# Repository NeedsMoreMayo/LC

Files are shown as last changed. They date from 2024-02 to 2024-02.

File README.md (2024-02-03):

# LC meter
The LC meter in this project is based on a popular design that's found on numerous websites. I added an external GPSDO input to use as stable clock reference and a second input so the meter can be used as a frequency counter.

## Principle of operation

## Major components
- The display is a 1602A (ver 5.5) with an I2C PCF8574 expander from aliExpress.
- uC is AVR32DB28

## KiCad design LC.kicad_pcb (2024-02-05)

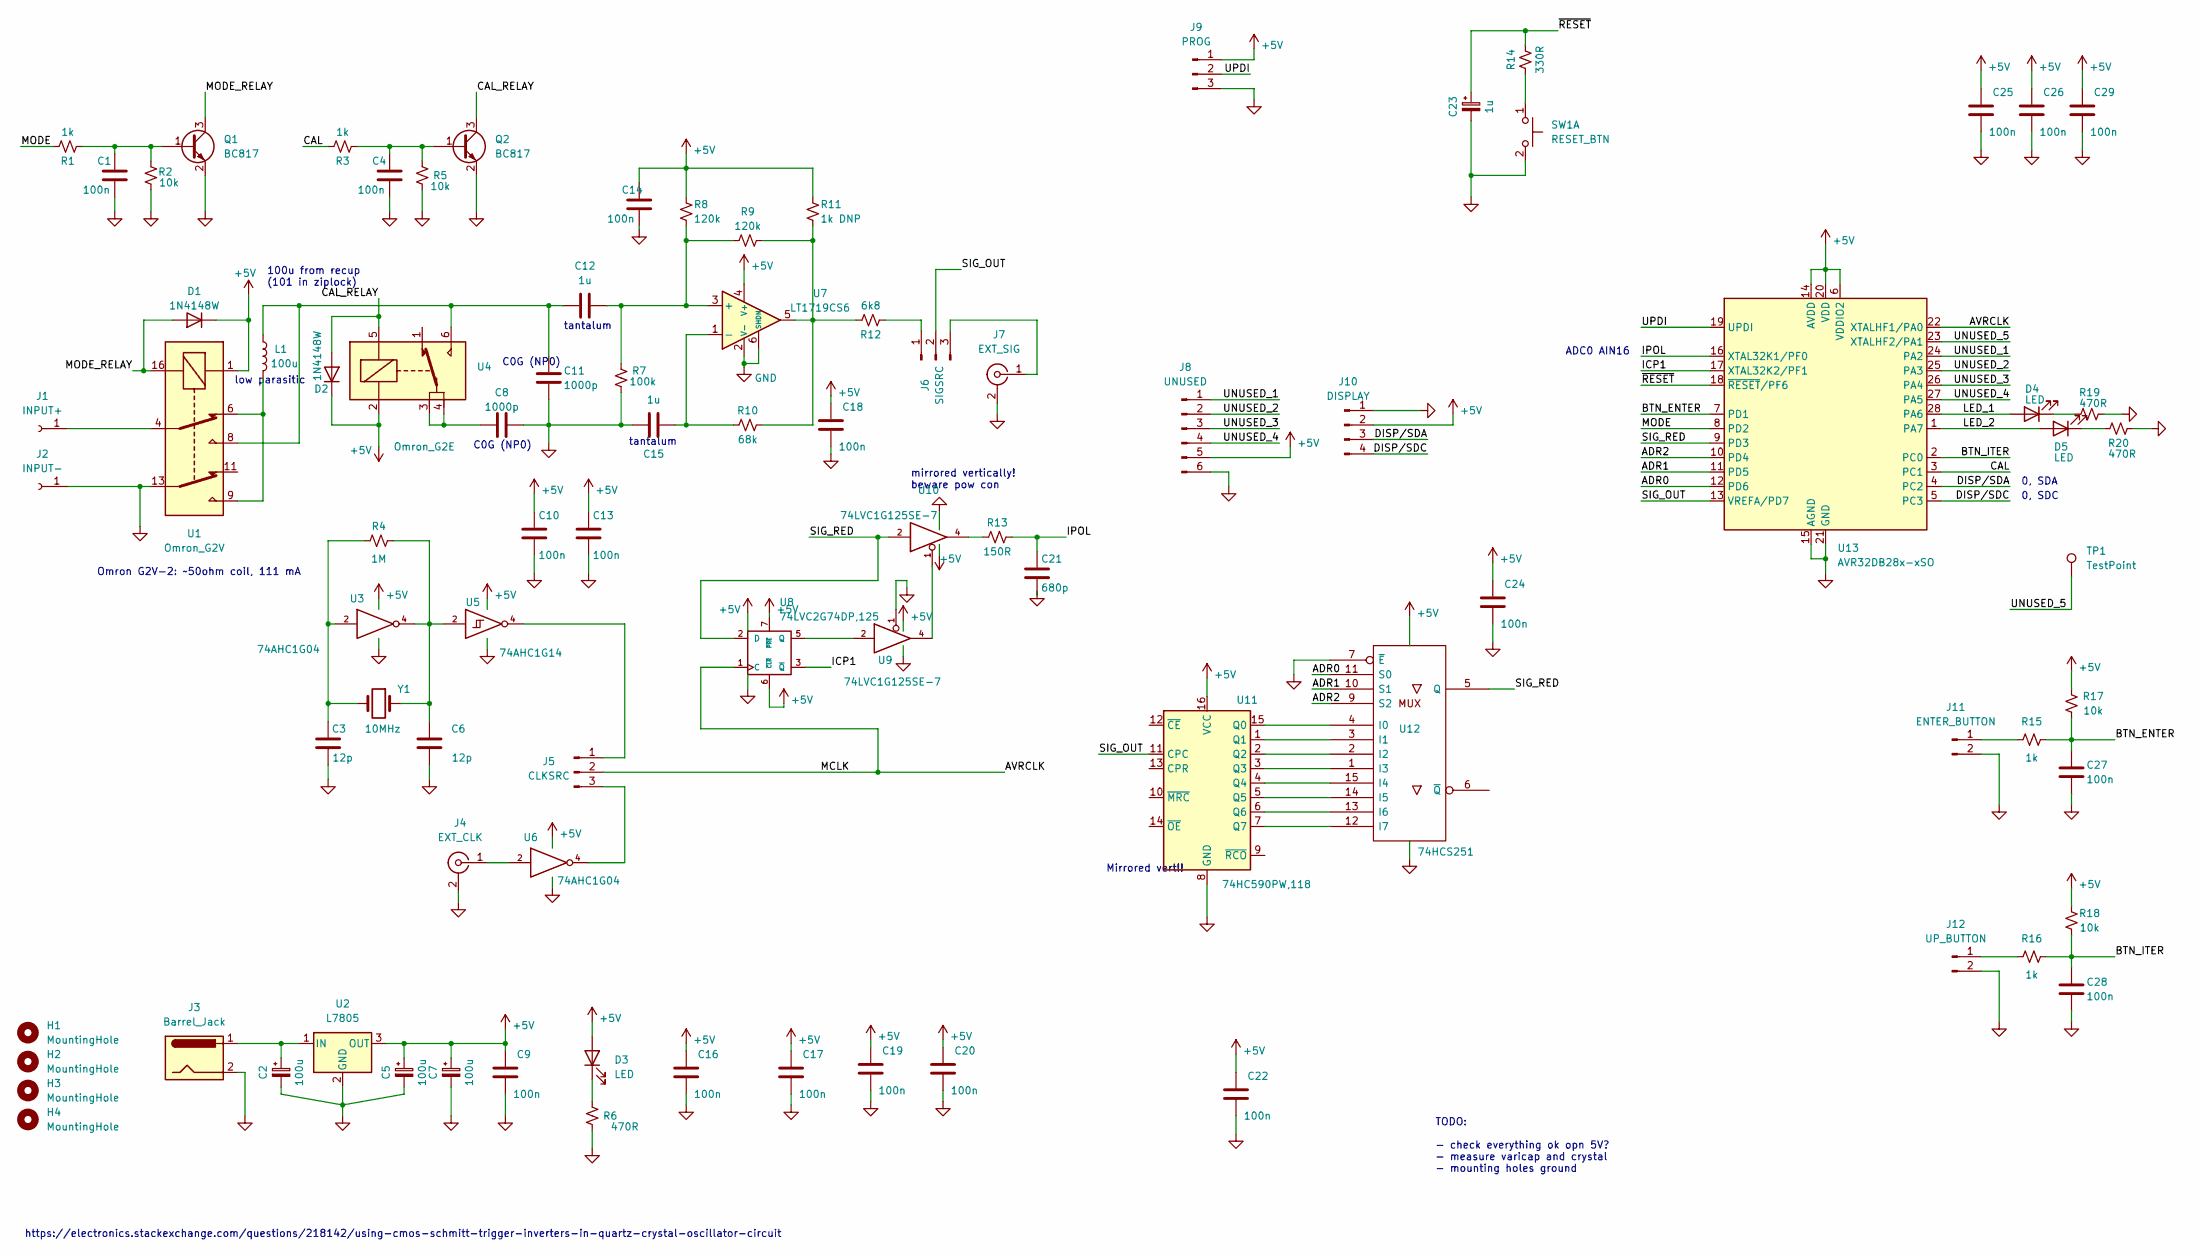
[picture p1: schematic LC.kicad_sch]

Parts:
C1, C4, C9, C10, C13, C14, C16, C17, C18, C19, C20, C22, C24, C25, C26, C27, C28, C29: 100n; C_0805_2012Metric_Pad1.18x1.45mm_HandSolder
C2, C5, C7: 100u; CP_Radial_D5.0mm_P2.00mm
C3, C6: 12p; C_0805_2012Metric_Pad1.18x1.45mm_HandSolder
C8, C11: 1000p; C_0805_2012Metric_Pad1.18x1.45mm_HandSolder
C12, C15, C23: 1u; C_0805_2012Metric_Pad1.18x1.45mm_HandSolder
C21: 680p; C_0805_2012Metric_Pad1.18x1.45mm_HandSolder
D1, D2: 1N4148W; D_SOD-123
D3, D4, D5: LED; LED_1206_3216Metric
H1, H2, H3, H4: MountingHole; MountingHole_3.2mm_M3_Pad
J1: INPUT+; Pin_D1.0mm_L10.0mm
J2: INPUT-; Pin_D1.0mm_L10.0mm
J3: Barrel_Jack; BarrelJack_GCT_DCJ200-10-A_Horizontal
J4: EXT_CLK; U.FL_Molex_MCRF_73412-0110_Vertical
J5: CLKSRC; PinHeader_1x03_P2.54mm_Vertical
J6: SIGSRC; PinHeader_1x03_P2.54mm_Vertical
J7: EXT_SIG; U.FL_Molex_MCRF_73412-0110_Vertical
J8: UNUSED; PinHeader_2x03_P2.54mm_Vertical
J9: PROG; PinHeader_1x03_P2.54mm_Vertical
J10: DISPLAY; PinHeader_1x04_P2.54mm_Vertical
J11: ENTER_BUTTON; PinHeader_1x02_P2.54mm_Vertical
J12: UP_BUTTON; PinHeader_1x02_P2.54mm_Vertical
L1: 100u; L_Coilcraft_LPS5030
Q1, Q2: BC817; SOT-23
R1, R3, R15, R16: 1k; R_0805_2012Metric_Pad1.20x1.40mm_HandSolder
R2, R5, R17, R18: 10k; R_0805_2012Metric_Pad1.20x1.40mm_HandSolder
R4: 1M; R_0805_2012Metric_Pad1.20x1.40mm_HandSolder
R6, R19, R20: 470R; R_0805_2012Metric_Pad1.20x1.40mm_HandSolder
R7: 100k; R_0805_2012Metric_Pad1.20x1.40mm_HandSolder
R8, R9: 120k; R_0805_2012Metric_Pad1.20x1.40mm_HandSolder
R10: 68k; R_0805_2012Metric_Pad1.20x1.40mm_HandSolder
R11: 1k DNP; R_0805_2012Metric_Pad1.20x1.40mm_HandSolder
R12: 6k8; R_0805_2012Metric_Pad1.20x1.40mm_HandSolder
R13: 150R; R_0805_2012Metric_Pad1.20x1.40mm_HandSolder
R14: 330R; R_0805_2012Metric_Pad1.20x1.40mm_HandSolder
SW1: RESET_BTN; BUTTON_5X5
TP1: TestPoint; TestPoint_THTPad_1.0x1.0mm_Drill0.5mm
U1: Omron_G2V; Omron G2V-2
U2: L7805; TO-220-3_Vertical
U3, U6: 74AHC1G04; SOT-23-5_HandSoldering
U4: Omron_G2E; Omron G2E
U5: 74AHC1G14; SOT-23-5_HandSoldering
U7: LT1719CS6; SOT-23-6
U8: 74LVC2G74DP,125; TSSOP-8_3x3mm_P0.65mm
U9, U10: 74LVC1G125SE-7; SOT-353_SC-70-5
U11: 74HC590PW,118; TSSOP-16_4.4x5mm_P0.65mm
U12: 74HCS251; SOIC-16_4.55x10.3mm_P1.27mm
U13: AVR32DB28x-xSO; SOIC-28W_7.5x17.9mm_P1.27mm
Y1: 10MHz; Crystal_HC49-4H_Vertical

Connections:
+5V: C5.1, C7.1, C9.2, C10.2, C13.2, C14.2, C16.2, C17.2, C18.2, C19.2, C20.2, C22.2, C24.2, C25.2, C26.2, C29.2, D1.1 (K), D2.1 (K), D3.2 (A), J8.5, J9.1, J10.2, R8.2, R11.2, R17.1, R18.1, U1.1, U2.3 (OUT), U3.5 (VCC), U4.2, U5.5 (VCC), U6.5 (VCC), U7.4 (V+), U8.6 (~CLR), U8.7 (~PRE), U8.8 (VCC), U9.5 (VCC), U10.5 (VCC), U11.16 (VCC), U12.16 (VCC), U13.6 (VDDIO2), U13.14 (AVDD), U13.20 (VDD)
/ADR0: U12.11 (S0), U13.12 (PD6)
/ADR1: U12.10 (S1), U13.11 (PD5)
/ADR2: U12.9 (S2), U13.10 (PD4)
/AVRCLK: J5.2, U8.1 (C), U13.22 (XTALHF1/PA0)
/BTN_ENTER: C27.2, R15.2, R17.2, U13.7 (PD1)
/BTN_ITER: C28.2, R16.2, R18.2, U13.2 (PC0)
/CAL: R3.2, U13.3 (PC1)
/CAL_RELAY: D2.2 (A), Q2.3 (C), U4.5
/DISP/SDA: J10.3, U13.4 (PC2)
/DISP/SDC: J10.4, U13.5 (PC3)
/ICP1: U8.3 (~Q), U13.17 (XTAL32K2/PF1)
/IPOL: C21.2, R13.1, U13.16 (XTAL32K1/PF0)
/LED_1: D4.2 (A), U13.28 (PA6)
/LED_2: D5.2 (A), U13.1 (PA7)
/MODE: R1.2, U13.8 (PD2)
/MODE_RELAY: D1.2 (A), Q1.3 (C), U1.16
/SIG_OUT: J6.2, U11.11 (CPC), U13.13 (VREFA/PD7)
/SIG_RED: U8.2 (D), U10.2, U12.5 (Q), U13.9 (PD3)
/UNUSED_1: J8.1, U13.24 (PA2)
/UNUSED_2: J8.2, U13.25 (PA3)
/UNUSED_3: J8.3, U13.26 (PA4)
/UNUSED_4: J8.4, U13.27 (PA5)
/UNUSED_5: TP1.1, U13.23 (XTALHF2/PA1)
/UPDI: J9.2, U13.19 (UPDI)
/~RESET: C23.1, R14.2, U13.18 (~RESET/PF6)
GND: C1.1, C2.2, C3.2, C4.1, C5.2, C6.2, C7.2, C8.1, C9.1, C10.1, C11.1, C13.1, C14.1, C15.1, C16.1, C17.1, C18.1, C19.1, C20.1, C21.1, C22.1, C23.2, C24.1, C25.1, C26.1, C27.1, C28.1, C29.1, J2.1, J3.2, J4.2 (Ext), J7.2 (Ext), J8.6, J9.3, J10.1, J11.2, J12.2, Q1.2 (E), Q2.2 (E), R2.2, R5.2, R6.2, R7.1, R19.2, R20.2, SW1.2 (D), U1.13, U2.2 (GND), U3.3 (GND), U5.3 (GND), U6.3 (GND), U7.2 (V-), U7.6 (SHDN), U8.4 (GND), U9.1, U9.3 (GND), U10.3 (GND), U11.8 (GND), U12.7 (~E), U12.8 (GND), U13.15 (AGND), U13.21 (GND)
unnamed: C1.2, Q1.1 (B), R1.1, R2.1
unnamed: C2.1, J3.1, U2.1 (IN)
unnamed: C3.1, R4.1, U3.2, Y1.2
unnamed: C4.2, Q2.1 (B), R3.1, R5.1
unnamed: C6.1, R4.2, U3.4, U5.2, Y1.1
unnamed: C8.2, U4.3, U4.4
unnamed: C11.2, C12.1, L1.1, U1.8, U4.6
unnamed: C12.2, R7.2, R8.1, R9.1, U7.3 (+)
unnamed: C15.2, R10.1, U7.1 (-)
unnamed: D3.1 (K), R6.1
unnamed: D4.1 (K), R19.1
unnamed: D5.1 (K), R20.1
unnamed: J1.1, U1.4
unnamed: J4.1 (In), U6.2
unnamed: J5.1, U5.4
unnamed: J5.3, U6.4
unnamed: J6.1, R12.1
unnamed: J6.3, J7.1 (In)
unnamed: J11.1, R15.1
unnamed: J12.1, R16.1
unnamed: L1.2, U1.6, U1.9
unnamed: R9.2, R10.2, R11.1, R12.2, U7.5
unnamed: R13.2, U10.4
unnamed: R14.1, SW1.1 (C)
unnamed: U8.5 (Q), U9.2
unnamed: U9.4, U10.1
unnamed: U11.1 (Q1), U12.3 (I1)
unnamed: U11.2 (Q2), U12.2 (I2)
unnamed: U11.3 (Q3), U12.1 (I3)
unnamed: U11.4 (Q4), U12.15 (I4)
unnamed: U11.5 (Q5), U12.14 (I5)
unnamed: U11.6 (Q6), U12.13 (I6)
unnamed: U11.7 (Q7), U12.12 (I7)
unnamed: U11.15 (Q0), U12.4 (I0)

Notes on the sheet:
100u from recup (101 in ziplock)
C0G (NP0)
mirrored vertically! beware pow con
low parasitic
0, SDC
TODO: - check everything ok opn 5V? - measure varicap and crystal - mounting holes ground
tantalum
Mirrored vert!!
Omron G2V-2: ~50ohm coil, 111 mA
ADC0 AIN16
0, SDA
https://electronics.stackexchange.com/questions/218142/using-cmos-schmitt-trigger-inverters-in-quartz-crystal-oscillator-circuit

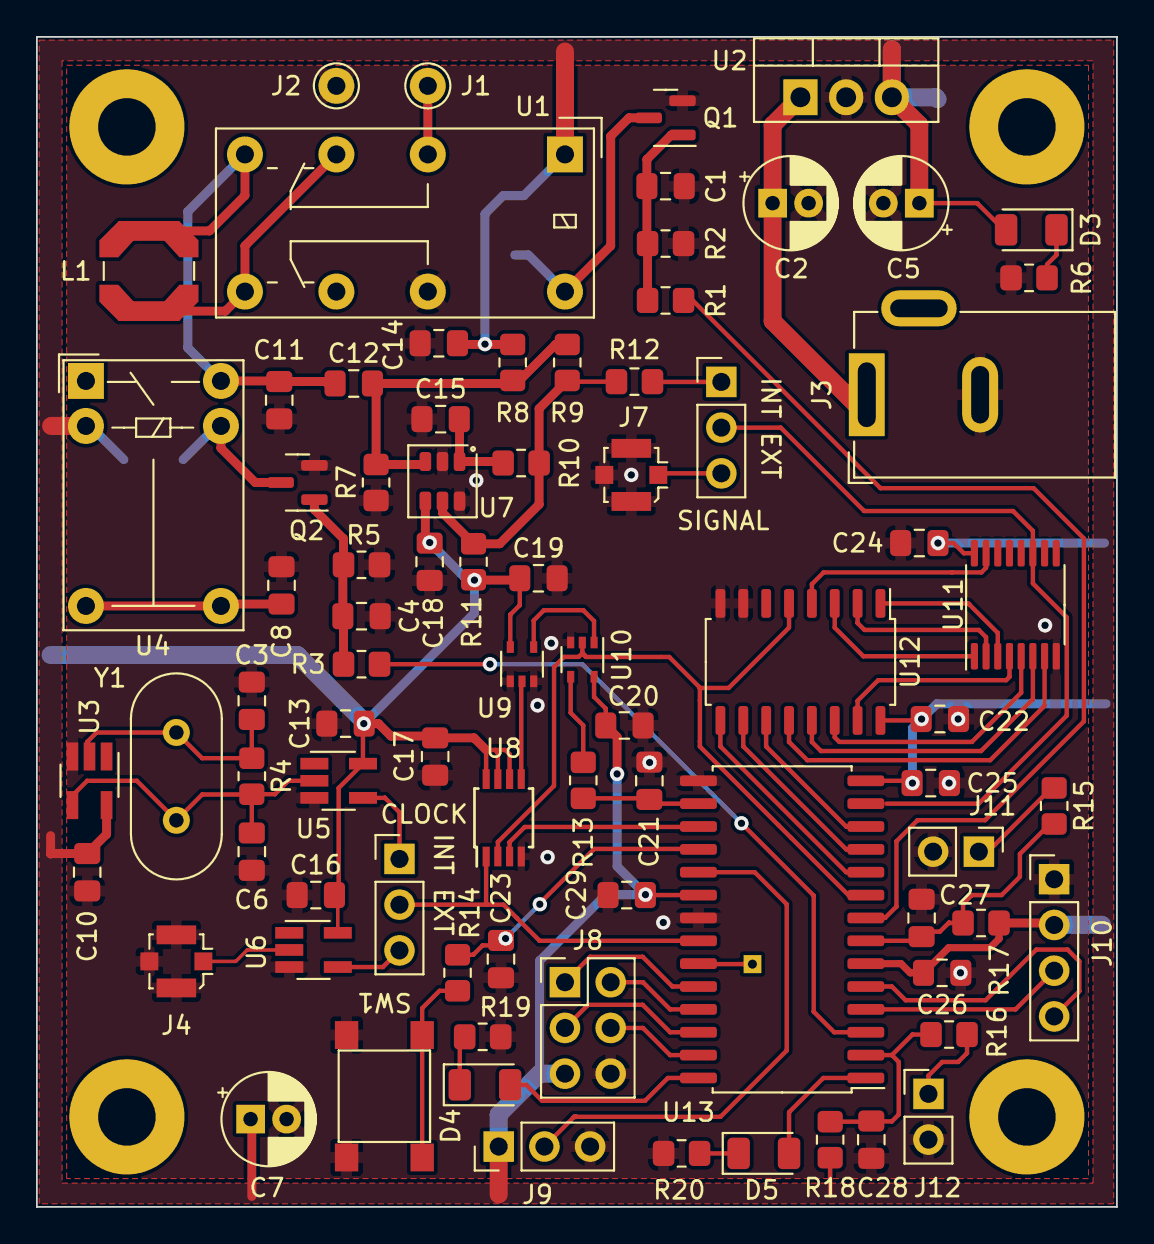
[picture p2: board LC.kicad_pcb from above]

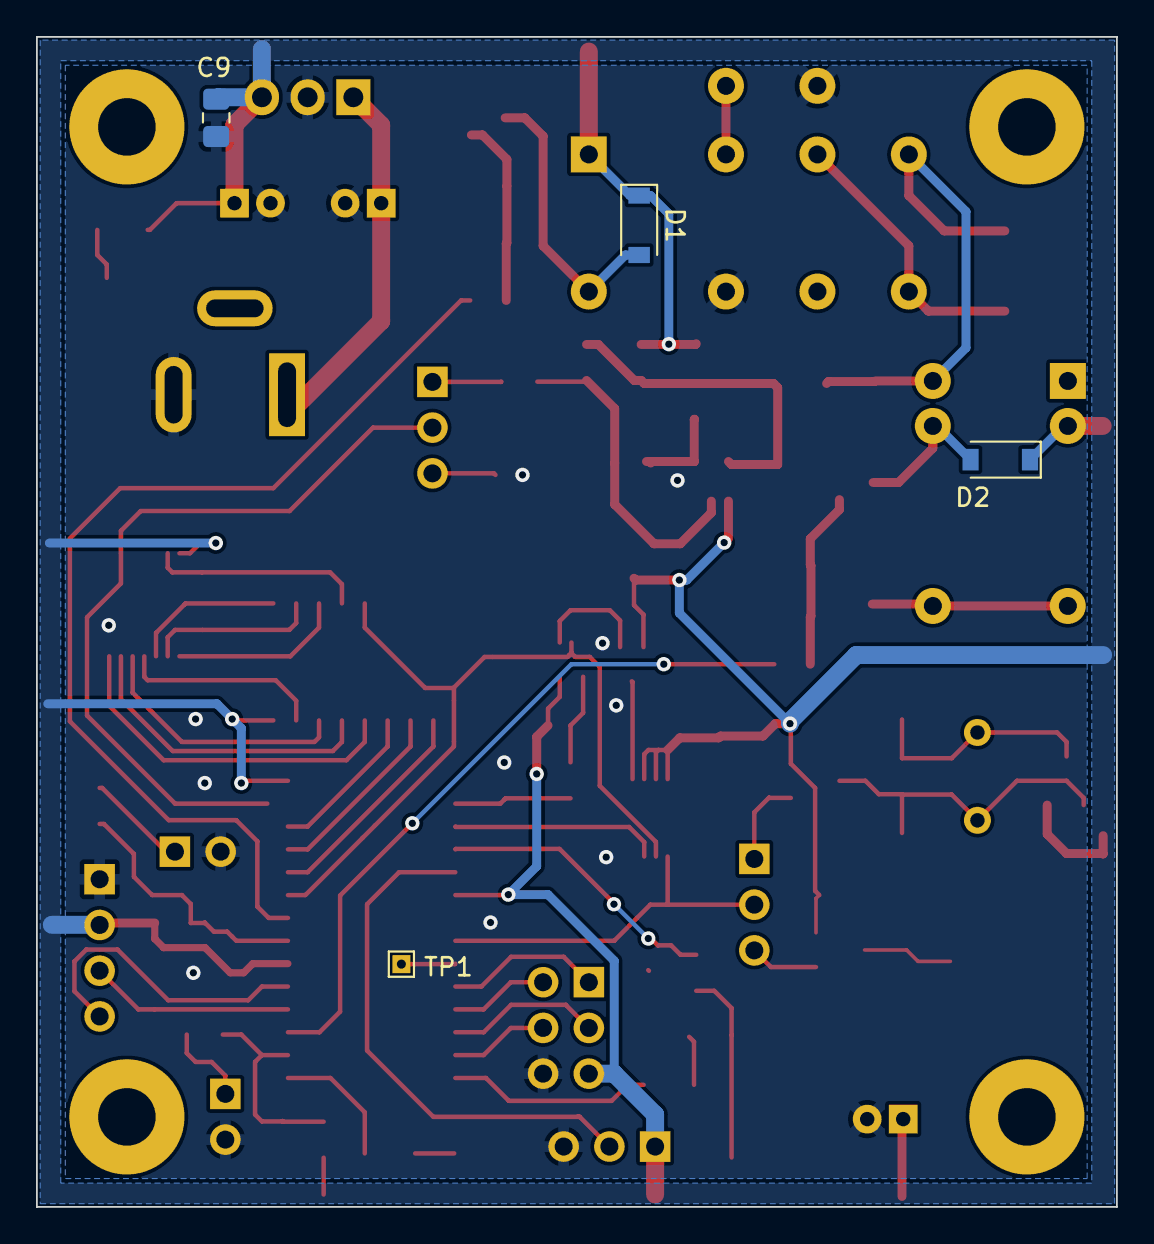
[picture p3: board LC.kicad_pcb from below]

Board: 2 copper layers, 60.0 x 65.0 mm, 89 parts (4 on the bottom side), 61 nets.

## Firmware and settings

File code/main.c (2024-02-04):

//F_CPU defined in makefile
//#define F_CPU 10000000ul

#include <avr/io.h>
#include <util/delay.h>		//temporary sin
#include <avr/interrupt.h>
//#include <math.h>

#include "LCD.h"


//PORT A
#define AVRCLK_PIN		0
#define CAL_PIN			1
#define UNUSED_1_PIN	2
#define UNUSED_2_PIN	3
#define UNUSED_3_PIN	4
#define UNUSED_4_PIN	5
#define LED_1_PIN		6
#define LED_2_PIN		7

//PORT C
#define BTN_ITER_PIN	0
#define UNUSED_5_PIN	1
#define DISP_SDA_PIN	2
#define DISP_SDC_PIN	3

//PORT D
#define BTN_ENTER_PIN	1	//ADC0 AIN1
#define MODE_PIN		2
#define SIG_RED_PIN		3
#define ADR2_PIN		4
#define ADR1_PIN		5
#define ADR0_PIN		6
#define SIG_OUT_PIN		7

//PORT F
#define IPOL_PIN		0
#define ICP1_PIN		1
#define RESET_PIN		6

void PORTS_init(void);
void I2C0_init(void);
void LCD_init(void);
void TOGGLE_LED(void);

int main(void){
	cli(); //disable interrupts when enabling interrupt handlers
	PORTS_init();
	I2C0_init();
	LCD_init();
	sei();//enable interrupts
    while (1){
		TOGGLE_LED();
		_delay_ms(1000);

		LCD1602_send_command(CLEAR_DISPLAY);
		_delay_us(100);
		LCD1602_send_command(RETURN_HOME);
		_delay_us(100);
		LCD1602_send_string("Testing 123");
		_delay_us(100);
    }
}


void TOGGLE_LED(){
	PORTD.OUTTGL = (1 << LED_1_PIN)
		 		|  (1 << LED_2_PIN);
}

void PORTS_init(){
	//CAL, LED_1 and LED_2 are output on PORTA
	PORTA.DIR =   (1 << CAL_PIN)
				| (1 << LED_1_PIN)
				| (1 << LED_2_PIN);
	PORTA.OUT = 0x00;
	
	//DISP_SDA and DISP_SDC are output on PORTC
	PORTC.DIR =   (1 << DISP_SDA_PIN)
				| (1 << DISP_SDC_PIN);
	PORTC.OUT = 0x00;
	
	//MODE and ADR0..2 are output on PORTD
	PORTD.DIR =   (1 << MODE_PIN)
				| (1 << ADR0_PIN)
				| (1 << ADR1_PIN)
				| (1 << ADR2_PIN);
	PORTD.OUT = 0x00;
	
	//no output on PORTD
	PORTF.DIR = 0;
	PORTF.OUT = 0x00;
}

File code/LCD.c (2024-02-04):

#include <avr/io.h>
#include <util/delay.h>		//temporary sin
#include <avr/interrupt.h>

#include <string.h>

#include "LCD.h"

#define TWI0_BAUD(F_SCL, T_RISE)	((((((float)5000000.0 / (float)F_SCL)) - 10 - ((float)5000000.0 * T_RISE / 1000000))) / 2)

#define I2C_LCD_ADDR_DEFAULT 		0x27


#define LCD_NOBACKLIGHT 			0x00	//from sunfounder code zip
#define	CLEAR_DISPLAY				0x01	//Clear display screen
#define	RETURN_HOME					0x02	//Return home
#define	CURSOR_DECR					0x04	//Decrement cursor (shift cursor to left)
#define	CURSOR_INCR					0x06	//Increment cursor (shift cursor to right)
#define	SHIFT_RIGHT					0x05	//Shift display right
#define	SHIFT_LEFT					0x07	//Shift display left
#define	DISP_OFF_CURSOR_OFF			0x08	//Display off, cursor off
#define	DISP_OFF_CURSOR_ON			0x0A	//Display off, cursor on
#define	DISP_ON_CURSOR_OFF			0x0C	//Display on, cursor off
#define	DISP_ON_CURSOR_NO_BLINK		0x0E	//Display on, cursor not blinking
#define	DISP_ON_CURSOR_BLINK		0x0F	//Display on, cursor blinking
#define	SHIFT_CURSOR_LEFT			0x10	//Shift cursor position to left
#define	SHIFT_CURSOR_RIGHT			0x14	//Shift the cursor position to the right
#define	SHIFT_DISP_LEFT				0x18	//Shift the entire display to the left
#define	SHIFT_DISP_RIGHT			0x1C	//Shift the entire display to the right
#define	DISP_2_X_5x7				0x28	//2 lines and 5×7 matrix

#define SEL_FIRST_LINE				0x80 //Force cursor to the beginning of 1st line
#define SEL_SECOND_LINE				0xC0 //Force cursor to the beginning of 2nd line

#define I2C_ACKED					0x01
#define I2C_NACKED					0x02
#define I2C_ERROR					0x03

char TEXTBUFF[16] = "It's Working";
uint8_t DATABUFF[64] = "";
char *textbuff = TEXTBUFF;
uint8_t *databuff = DATABUFF;

static uint8_t TWI0_WaitW(void){
	uint8_t state = 0;
	do{
		if(TWI0.MSTATUS & (TWI_WIF_bm | TWI_RIF_bm)){
			if(!(TWI0.MSTATUS & TWI_RXACK_bm)){
				/* slave responded with ack - TWI goes to M1 state */
				state = I2C_ACKED;
			}else{
				/* address sent but no ack received - TWI goes to M3 state */
				state = I2C_NACKED;
			}
		}else if(TWI0.MSTATUS & (TWI_BUSERR_bm | TWI_ARBLOST_bm)){
			/* get here only in case of bus error or arbitration lost - M4 state */
			state = I2C_ERROR;
		}
	} while(!state);
	return state;
}

uint8_t TWI0_write_address(uint8_t address){
	uint8_t state = 0;
	
	TWI0.MADDR = address; /* Transmitting the slave address */
	state = TWI0_WaitW(); /* wait for error code */
	return state;
}

uint8_t TWI0_write_data(uint8_t data){
	uint8_t state = 0;
	
	TWI0.MDATA = data; /* Transmitting the data */
	state = TWI0_WaitW(); /* wait for error code */
	return state;
}

uint8_t I2C_Write(uint8_t slaveAddr7b, uint8_t *data, uint8_t size){
	uint8_t idx =0;
	uint8_t state = 0;
	
	state = TWI0_write_address(slaveAddr7b);
	for(idx = 0; idx < size; idx++){
		state = TWI0_write_data(data[idx]);
	}
	TWI0.MCTRLB = TWI_MCMD_STOP_gc;
	return state;
}

void LCD1602_send_char(unsigned char data){
	uint8_t UB = data & 0xF0;
	uint8_t LB = (data & 0x0F) << 4;

	databuff[0] = UB | 0x0D;
	databuff[1] = UB | 0x09;
	databuff[2] = LB | 0x0D;
	databuff[3] = LB | 0x09;
	I2C_Write(I2C_LCD_ADDR_DEFAULT, databuff, 4);
}

void LCD1602_send_command(uint8_t data){
	uint8_t UB = data & 0xF0;
	uint8_t LB = (data & 0x0F) << 4;
	
	databuff[0] = UB | 0x04;
	databuff[1] = UB | 0x00;
	databuff[2] = LB | 0x04;
	databuff[3] = LB | 0x00;
	I2C_Write(I2C_LCD_ADDR_DEFAULT, databuff, 4);
}

void LCD1602_send_UB_command(uint8_t data){
	uint8_t UB = data & 0xF0;

	databuff[0] = UB | 0x04;
	databuff[1] = UB | 0x00;
	I2C_Write(I2C_LCD_ADDR_DEFAULT, databuff, 2);
}

void LCD1602_send_string(char * data){
	uint8_t len = strlen((const char *)data);
	
	for (uint8_t i = 0; i < len; i++) {
		uint8_t UB = data[i] & 0xF0;
		uint8_t LB = (data[i] & 0x0F) << 4;

		databuff[(i << 2) + 0] = UB | 0x0D;
		databuff[(i << 2) + 1] = UB | 0x09;
		databuff[(i << 2) + 2] = LB | 0x0D;
		databuff[(i << 2) + 3] = LB | 0x09;
	}
	I2C_Write(I2C_LCD_ADDR_DEFAULT, databuff, (len << 2));
}


void LCD_init(void){
	_delay_ms(15);
	LCD1602_send_UB_command(0x30);	//D7=0, D6=0, D5=1, D4=1, RS,RW=0 EN=1
	_delay_us(4100);	//wait 4.1msec
	LCD1602_send_UB_command(0x30);	//D7=0, D6=0, D5=1, D4=1, RS,RW=0 EN=1
	_delay_us(100);	//wait 100usec
	LCD1602_send_UB_command(0x30);	//8-bit mode init complete
	_delay_us(4100);	//wait 4.1msec
	LCD1602_send_UB_command(0x20);	//switched now to 4-bit mode
	
	_delay_us(40);		// wait 40usec
	LCD1602_send_command(DISP_2_X_5x7);		// keep 4-bit mode, D3=2lines, D2=char5x8
	_delay_us(40);		// wait 40usec
	LCD1602_send_command(DISP_OFF_CURSOR_OFF);		// D3=1 D2=display_off, D1=cursor_off, D0=cursor_blink
	_delay_us(40);		// wait 40usec
	LCD1602_send_command(CLEAR_DISPLAY);		// D0=display_clear
	_delay_us(40);		// wait 40usec
	LCD1602_send_command(CURSOR_INCR);		// print left to right
	_delay_us(40);		// wait 40usec
	LCD1602_send_command(DISP_ON_CURSOR_BLINK);		// D3=1 D2=display_on, D1=cursor_on, D0=cursor_blink 0X0E
}


void I2C0_init(void){
	//PC2 = SDA
	//PC3 = SDC
	PORTMUX.TWIROUTEA = PORTMUX_TWI0_ALT2_gc; /* SDA: PC2, SCL: PC3. Dual mode: SDA: -, SCL: -. */
	//PCF8574 max 100kHz clock
	TWI0.MBAUD = (uint8_t)TWI0_BAUD(50000, 0); /* set MBAUD register */
	TWI0.MCTRLB =  TWI_FLUSH_bm;           // Clear TWI state (alternative: TWI_ACKACT_NACK_gc;  // send NACK)
	TWI0.MCTRLA = 1 << TWI_ENABLE_bp /* Enable TWI Master: enabled */
				| 0 << TWI_QCEN_bp /* Quick Command Enable: disabled */
				| 0 << TWI_RIEN_bp /* Read Interrupt Enable: disabled */
				| 0 << TWI_SMEN_bp /* Smart Mode Enable: disabled */
				| TWI_TIMEOUT_DISABLED_gc /* Bus Timeout Disabled */
				| 0 << TWI_WIEN_bp; /* Write Interrupt Enable: disabled */
	TWI0.MSTATUS |= TWI_BUSSTATE_IDLE_gc;   //initially sets the bus state to idle (alternative: TWI0.MSTATUS = 0xFF;)
}

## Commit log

2024-02-02 update display connector
    [LC.kicad_pcb, LC.kicad_sch]
2024-02-02 Unused IO to connector and LCD connector
    [LC.kicad_pcb, LC.kicad_sch]
2024-02-03 update gitignore and init code
    [LC.kicad_pcb, LC.kicad_sch]
2024-02-03 changed comparator: LM311 became TLV3201
    [LC.kicad_pcb, LC.kicad_sch]
2024-02-03 R11 is Do Not Populate
    [LC.kicad_sch]
2024-02-04 Updated comparator oscillator with LTSpice simulation results
    LT1719 operates nicely, but some values need to be adjusted. Especially the coupling caps need to be changed (10u -> 1u) so I decided to change them to MLCC.
    [LC.kicad_pcb, LC.kicad_sch]
2024-02-04 Updated schematic for 5V devices in TIC, PCB is in todo
    [LC.kicad_pcb, LC.kicad_sch]
2024-02-05 Updated schematic with correct 5V devices
    [LC.kicad_pcb, LC.kicad_sch]
2024-02-05 forgot that polystyrene are THT
    [LC.kicad_sch]
2024-02-05 a few more pin swaps
    [LC.kicad_pcb, LC.kicad_sch]
